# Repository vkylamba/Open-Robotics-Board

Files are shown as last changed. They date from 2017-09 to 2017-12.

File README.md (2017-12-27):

# Open-Robotics-Board
Open robotics development board

## Board Specifications
1. ATmega2560 microcontroller.
2. 6 L293d motor drives chips with terminal blocks to connect motor/LEDs.
3. Ports to connect WiFi, and GPRS.
4. On board 16x2 LCD.
5. On board USB port to program the board, and for serial communication.
6. Can be power from 5V-35V.
7. 5 analog ports with female barrel jacks(2 of them can accept high voltages, and are isolated).

## Board Image
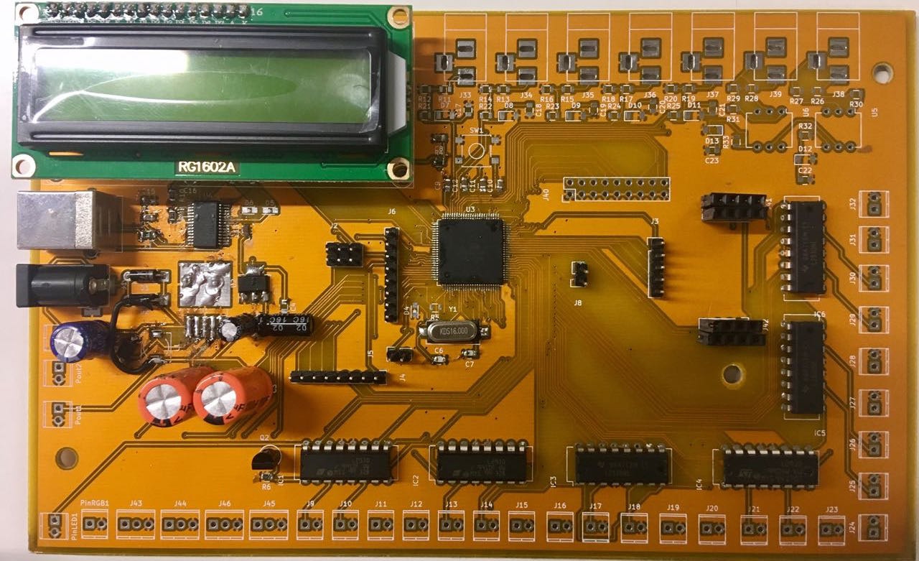
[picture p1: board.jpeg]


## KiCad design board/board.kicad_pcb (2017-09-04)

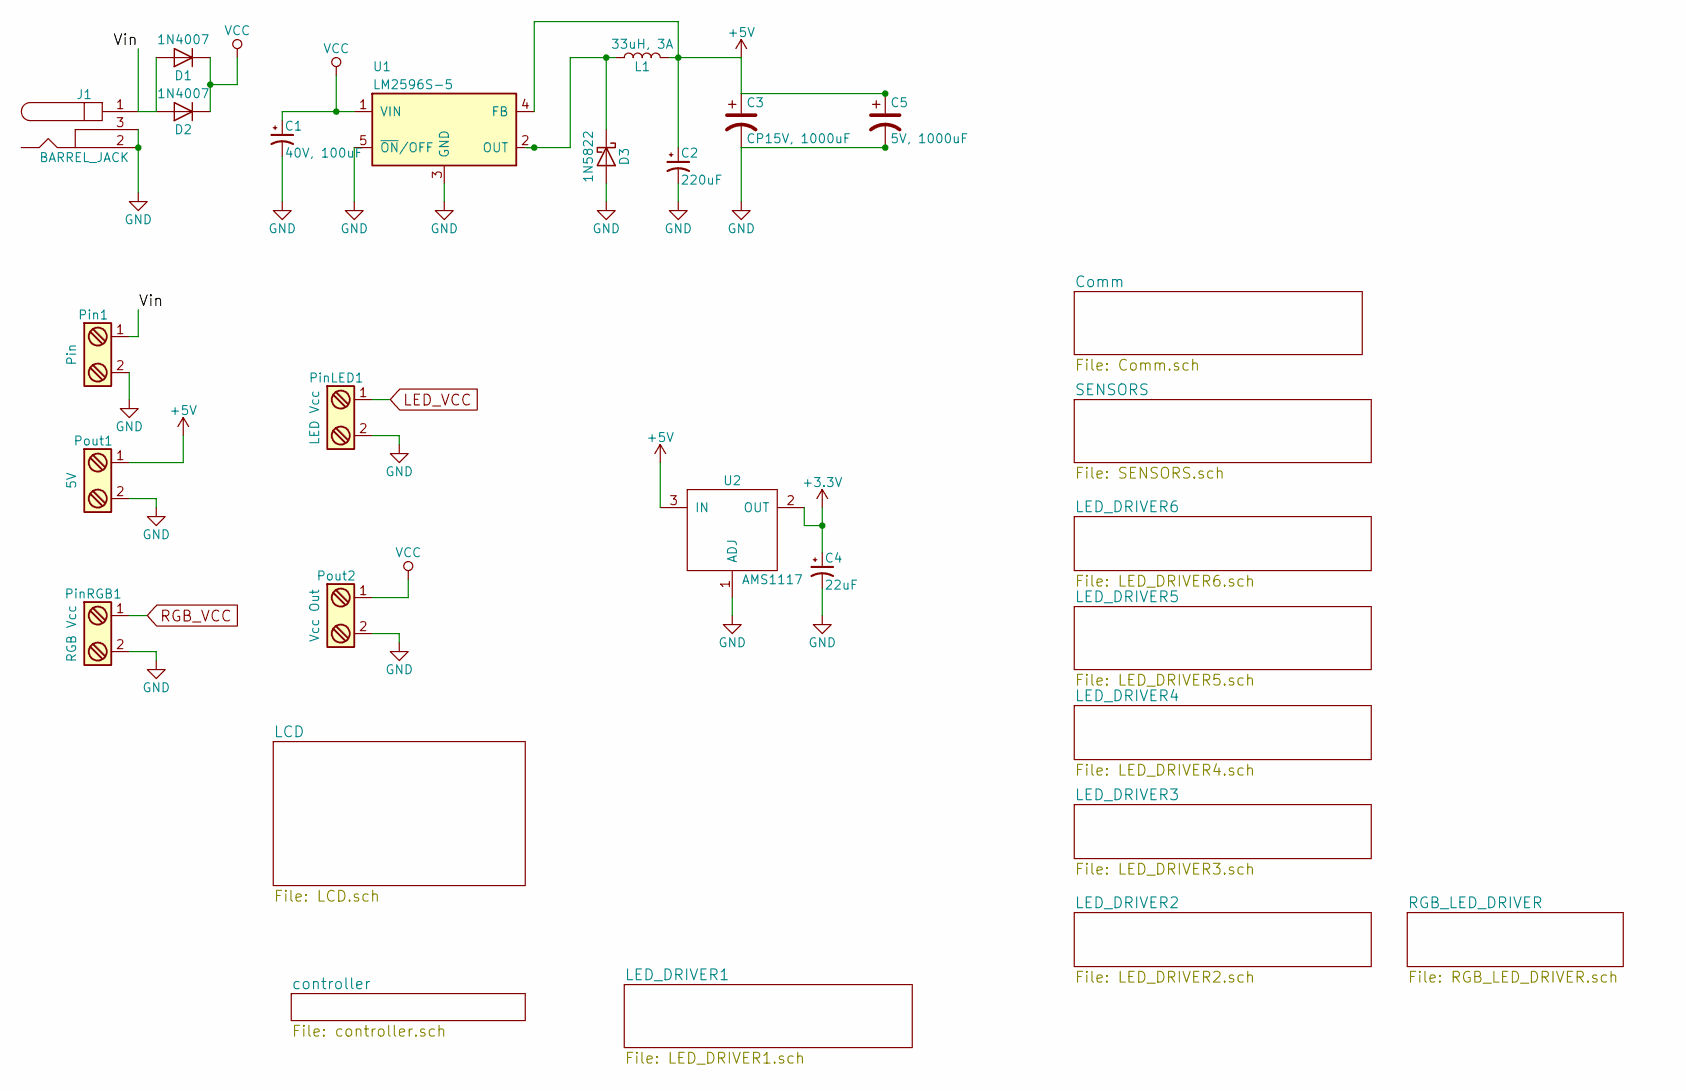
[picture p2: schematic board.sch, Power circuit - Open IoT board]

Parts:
C1: 40V, 100uF; CP_Radial_D5.0mm_P2.50mm
C2: 220uF; CP_Radial_D5.0mm_P2.50mm
C3: CP15V, 1000uF; CP_Radial_D8.0mm_P3.80mm
C4: 22uF; C_0805
C5: 5V, 1000uF; CP_Radial_D8.0mm_P3.80mm
D1, D2: 1N4007; D_DO-41_SOD81_P7.62mm_Horizontal
D3: 1N5822; D_1206
J1: BARREL_JACK
L1: 33uH, 3A; Choke_SMD_6.3x6.3_H3
Pin1: Pin; TerminalBlock_Pheonix_MPT-2.54mm_2pol
PinLED1: LED Vcc; TerminalBlock_Pheonix_MPT-2.54mm_2pol
PinRGB1: RGB Vcc; TerminalBlock_Pheonix_MPT-2.54mm_2pol
Pout1: 5V; TerminalBlock_Pheonix_MPT-2.54mm_2pol
Pout2: Vcc Out; TerminalBlock_Pheonix_MPT-2.54mm_2pol
U1: LM2596S-5; TO-263-5Lead
U2: AMS1117; SOT-223-3Lead_TabPin2

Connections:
+3V3: C4.1, U2.2 (OUT); also elsewhere on the board
+5V: C2.1, C3.1, C5.1, L1.2, Pout1.1, U1.4 (FB), U2.3 (IN); also elsewhere on the board
/Vin: D1.2 (A), D2.2 (A), J1.1, Pin1.1
GND: C1.2, C2.2, C3.2, C4.2, C5.2, D3.2 (A), J1.2, J1.3, Pin1.2, PinLED1.2, PinRGB1.2, Pout1.2, Pout2.2, U1.3 (GND), U1.5 (~ON~/OFF), U2.1 (ADJ); also elsewhere on the board
LED_VCC: PinLED1.1; also elsewhere on the board
unnamed: D3.1 (K), L1.1, U1.2 (OUT)
RGB_VCC: PinRGB1.1; also elsewhere on the board
VCC: C1.1, D1.1 (K), D2.1 (K), Pout2.1, U1.1 (VIN)

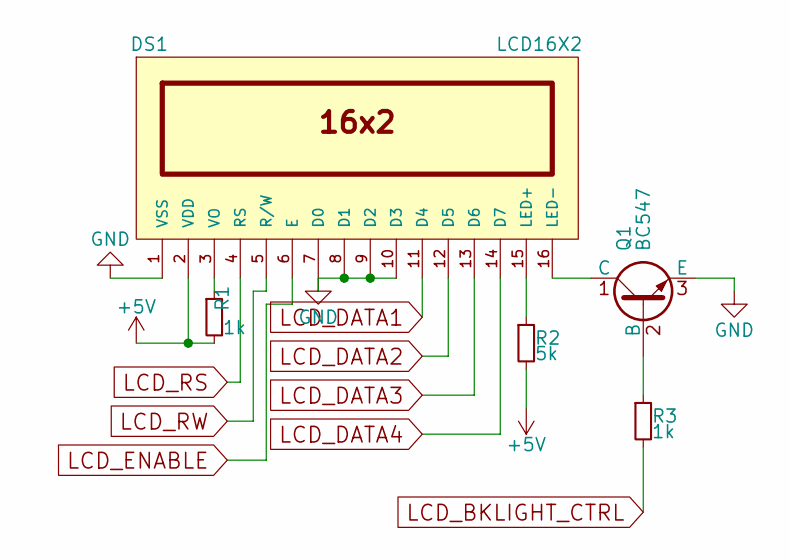
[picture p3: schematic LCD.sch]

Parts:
DS1: LCD16X2; WC1602A
Q1: BC547; TO-92_Inline_Narrow_Oval
R1, R3: 1k; R_0805
R2: 5k; R_0805

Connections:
+5V: DS1.2 (VDD), R1.2, R2.2; also elsewhere on the board
GND: DS1.1 (VSS), DS1.7 (D0), DS1.8 (D1), DS1.9 (D2), DS1.10 (D3), Q1.3 (E); also elsewhere on the board
LCD_BKLIGHT_CTRL: R3.2; also elsewhere on the board
LCD_DATA1: DS1.11 (D4); also elsewhere on the board
LCD_DATA2: DS1.12 (D5); also elsewhere on the board
LCD_DATA3: DS1.13 (D6); also elsewhere on the board
LCD_DATA4: DS1.14 (D7); also elsewhere on the board
LCD_ENABLE: DS1.6 (E); also elsewhere on the board
LCD_RS: DS1.4 (RS); also elsewhere on the board
LCD_RW: DS1.5 (R/W); also elsewhere on the board
unnamed: DS1.3 (VO), R1.1
unnamed: DS1.15 (LED+), R2.1
unnamed: DS1.16 (LED-), Q1.1 (C)
unnamed: Q1.2 (B), R3.1

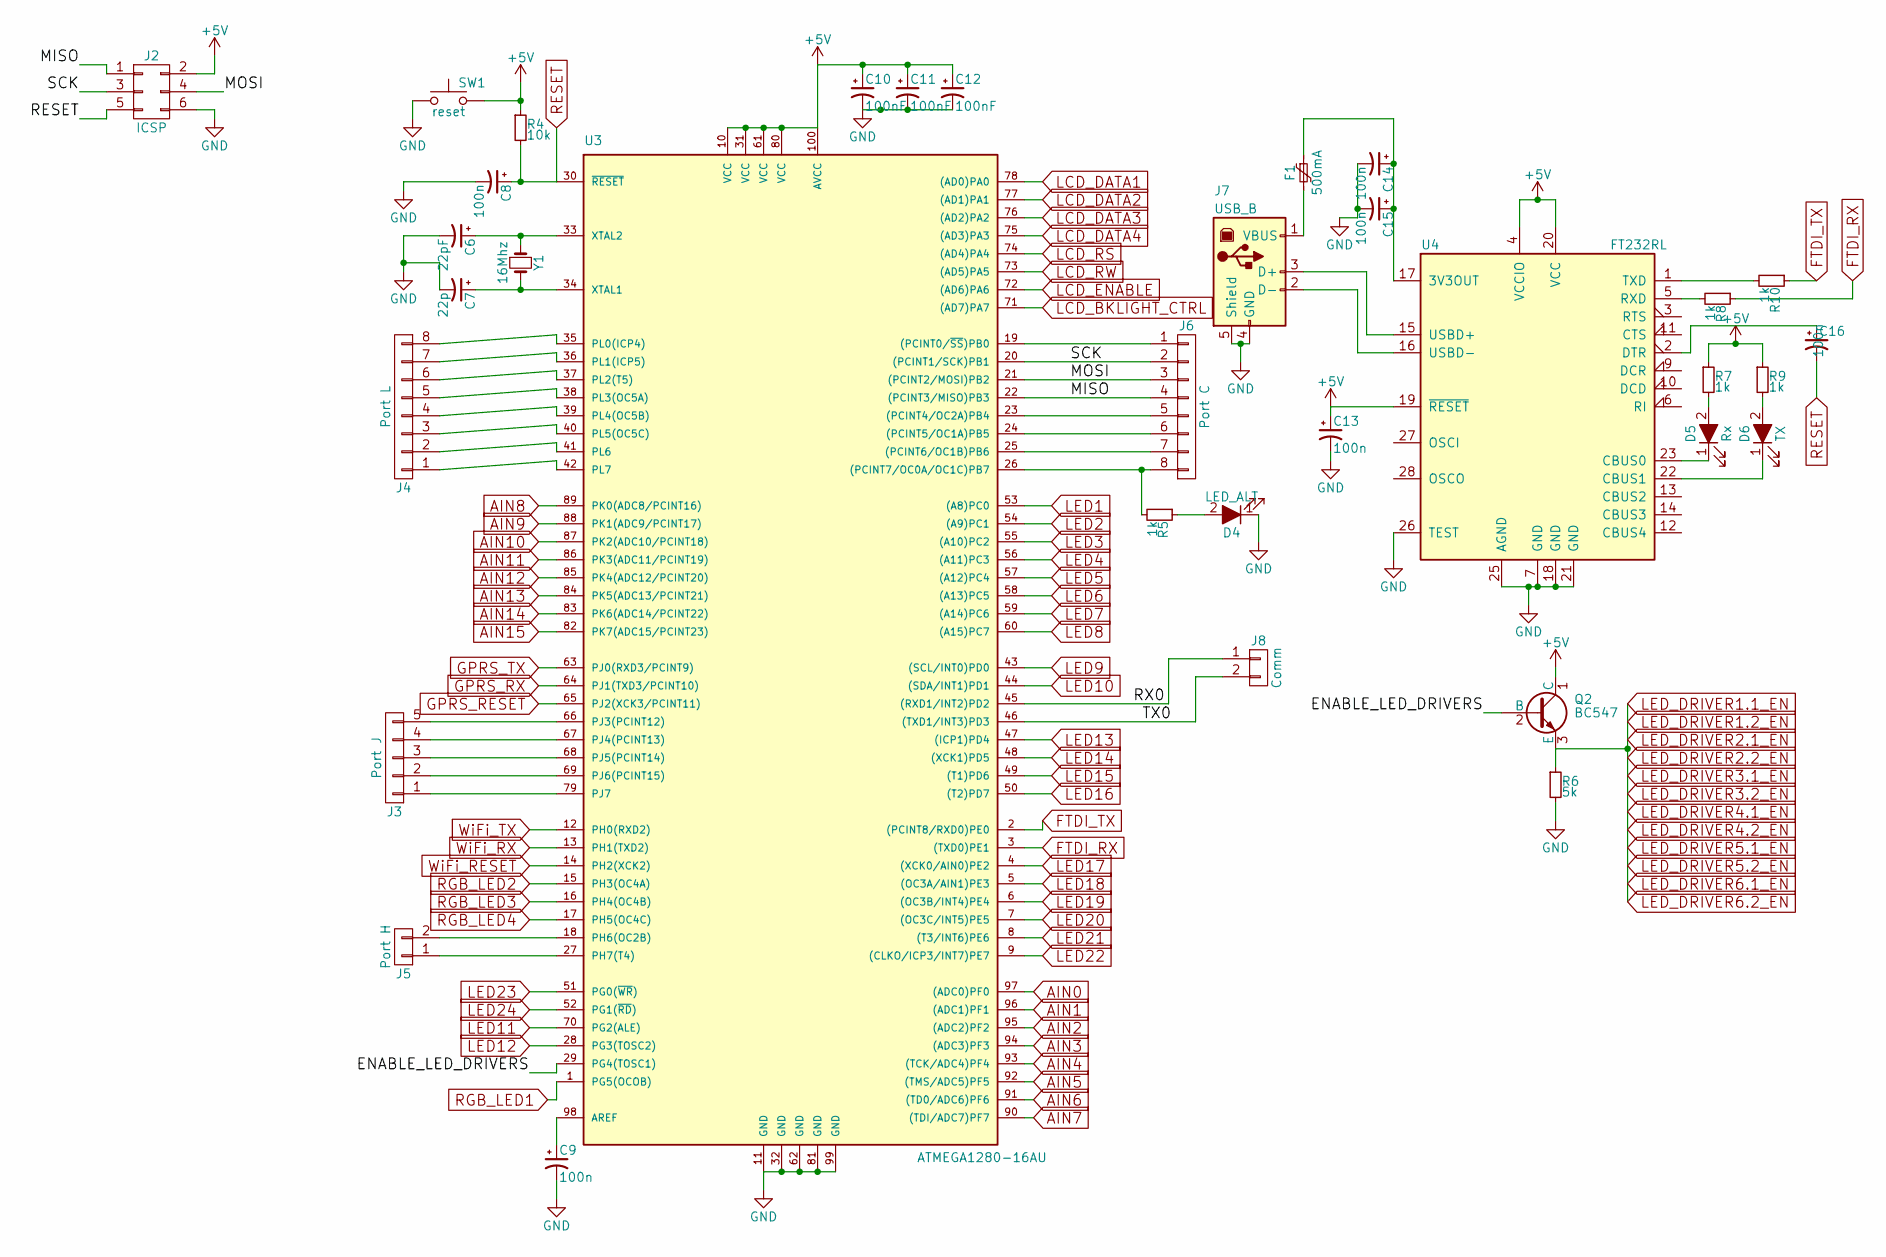
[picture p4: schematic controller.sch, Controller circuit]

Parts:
C6: 22pF; C_0805
C7: 22p; C_0805
C8, C9, C13, C14, C15, C16: 100n; C_0805
C10, C11, C12: 100nF; C_0805
D4: LED_ALT; LED_0805
D5: Rx; LED_0805
D6: TX; LED_0805
F1: 500mA; R_1206
J2: ICSP; Socket_Strip_Straight_2x03
J3: Port J; Pin_Header_Straight_1x05
J4: Port L; Pin_Header_Straight_1x08
J5: Port H; Pin_Header_Straight_1x02
J6: Port C; Pin_Header_Straight_1x08
J7: USB_B
J8: Comm; Pin_Header_Straight_1x02
Q2: BC547; TO-92_Inline_Narrow_Oval
R4: 10k; R_0805
R5, R7, R8, R9, R10: 1k; R_0805
R6: 5k; R_0805
SW1: reset; SW_SPST_B3S-1000
U3: ATMEGA1280-16AU; TQFP-100_14x14mm_Pitch0.5mm
U4: FT232RL; SSOP-28_5.3x10.2mm_Pitch0.65mm
Y1: 16Mhz; Crystal_HC49-SD_SMD

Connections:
+5V: C10.1, C11.1, C12.1, C13.1, J2.2, Q2.1 (C), R4.1, R7.1, R9.1, SW1.2, U3.10 (VCC), U3.31 (VCC), U3.61 (VCC), U3.80 (VCC), U3.100 (AVCC), U4.4 (VCCIO), U4.19 (~RESET~), U4.20 (VCC); also elsewhere on the board
/controller/ENABLE_LED_DRIVERS: Q2.2 (B), U3.29 (PG4(TOSC1))
/controller/MISO: J2.1, J6.4, U3.22 ((PCINT3/MISO)PB3)
/controller/MOSI: J2.4, J6.3, U3.21 ((PCINT2/MOSI)PB2)
/controller/RX0: J8.1, U3.45 ((RXD1/INT2)PD2)
/controller/SCK: J2.3, J6.2, U3.20 ((PCINT1/SCK)PB1)
/controller/TX0: J8.2, U3.46 ((TXD1/INT3)PD3)
AIN0: U3.97 ((ADC0)PF0); also elsewhere on the board
AIN1: U3.96 ((ADC1)PF1); also elsewhere on the board
AIN2: U3.95 ((ADC2)PF2); also elsewhere on the board
AIN3: U3.94 ((ADC3)PF3); also elsewhere on the board
AIN4: U3.93 ((TCK/ADC4)PF4); also elsewhere on the board
AIN5: U3.92 ((TMS/ADC5)PF5); also elsewhere on the board
AIN6: U3.91 ((TD0/ADC6)PF6); also elsewhere on the board
AIN7: U3.90 ((TDI/ADC7)PF7); also elsewhere on the board
AIN8: U3.89 (PK0(ADC8/PCINT16)); also elsewhere on the board
AIN9: U3.88 (PK1(ADC9/PCINT17)); also elsewhere on the board
AIN10: U3.87 (PK2(ADC10/PCINT18)); also elsewhere on the board
AIN11: U3.86 (PK3(ADC11/PCINT19)); also elsewhere on the board
AIN12: U3.85 (PK4(ADC12/PCINT20)); also elsewhere on the board
AIN13: U3.84 (PK5(ADC13/PCINT21)); also elsewhere on the board
AIN14: U3.83 (PK6(ADC14/PCINT22)); also elsewhere on the board
AIN15: U3.82 (PK7(ADC15/PCINT23)); also elsewhere on the board
FTDI_RX: R8.1, U3.3 ((TXD0)PE1)
FTDI_TX: R10.1, U3.2 ((PCINT8/RXD0)PE0)
GND: C6.2, C7.2, C8.2, C9.2, C10.2, C11.2, C12.2, C13.2, C14.2, C15.2, D4.1 (K), J2.6, J7.4 (GND), J7.5 (Shield), R6.2, SW1.1, U3.11 (GND), U3.32 (GND), U3.62 (GND), U3.81 (GND), U3.99 (GND), U4.7 (GND), U4.18 (GND), U4.21 (GND), U4.25 (AGND), U4.26 (TEST); also elsewhere on the board
GPRS_RESET: U3.65 (PJ2(XCK3/PCINT11)); also elsewhere on the board
GPRS_RX: U3.64 (PJ1(TXD3/PCINT10)); also elsewhere on the board
GPRS_TX: U3.63 (PJ0(RXD3/PCINT9)); also elsewhere on the board
LCD_BKLIGHT_CTRL: U3.71 ((AD7)PA7); also elsewhere on the board
LCD_DATA1: U3.78 ((AD0)PA0); also elsewhere on the board
LCD_DATA2: U3.77 ((AD1)PA1); also elsewhere on the board
LCD_DATA3: U3.76 ((AD2)PA2); also elsewhere on the board
LCD_DATA4: U3.75 ((AD3)PA3); also elsewhere on the board
LCD_ENABLE: U3.72 ((AD6)PA6); also elsewhere on the board
LCD_RS: U3.74 ((AD4)PA4); also elsewhere on the board
LCD_RW: U3.73 ((AD5)PA5); also elsewhere on the board
LED1: U3.53 ((A8)PC0); also elsewhere on the board
LED2: U3.54 ((A9)PC1); also elsewhere on the board
LED3: U3.55 ((A10)PC2); also elsewhere on the board
LED4: U3.56 ((A11)PC3); also elsewhere on the board
LED5: U3.57 ((A12)PC4); also elsewhere on the board
LED6: U3.58 ((A13)PC5); also elsewhere on the board
LED7: U3.59 ((A14)PC6); also elsewhere on the board
LED8: U3.60 ((A15)PC7); also elsewhere on the board
LED9: U3.43 ((SCL/INT0)PD0); also elsewhere on the board
LED10: U3.44 ((SDA/INT1)PD1); also elsewhere on the board
LED11: U3.70 (PG2(ALE)); also elsewhere on the board
LED12: U3.28 (PG3(TOSC2)); also elsewhere on the board
LED13: U3.47 ((ICP1)PD4); also elsewhere on the board
LED14: U3.48 ((XCK1)PD5); also elsewhere on the board
LED15: U3.49 ((T1)PD6); also elsewhere on the board
LED16: U3.50 ((T2)PD7); also elsewhere on the board
LED17: U3.4 ((XCK0/AIN0)PE2); also elsewhere on the board
LED18: U3.5 ((OC3A/AIN1)PE3); also elsewhere on the board
LED19: U3.6 ((OC3B/INT4)PE4); also elsewhere on the board
LED20: U3.7 ((OC3C/INT5)PE5); also elsewhere on the board
LED21: U3.8 ((T3/INT6)PE6); also elsewhere on the board
LED22: U3.9 ((CLKO/ICP3/INT7)PE7); also elsewhere on the board
LED23: U3.51 (PG0(~WR~)); also elsewhere on the board
LED24: U3.52 (PG1(~RD~)); also elsewhere on the board
LED_DRIVER1.1_EN: Q2.3 (E), R6.1; also elsewhere on the board
unnamed: C6.1, U3.33 (XTAL2), Y1.1
unnamed: C7.1, U3.34 (XTAL1), Y1.2
unnamed: C9.1, U3.98 (AREF)
unnamed: C14.1, C15.1, F1.1, U4.17 (3V3OUT)
unnamed: C16.1, U4.2 (DTR)
unnamed: D4.2 (A), R5.1
unnamed: D5.1 (K), U4.23 (CBUS0)
unnamed: D5.2 (A), R7.2
unnamed: D6.1 (K), U4.22 (CBUS1)
unnamed: D6.2 (A), R9.2
unnamed: F1.2, J7.1 (VBUS)
unnamed: J3.1, U3.79 (PJ7)
unnamed: J3.2, U3.69 (PJ6(PCINT15))
unnamed: J3.3, U3.68 (PJ5(PCINT14))
unnamed: J3.4, U3.67 (PJ4(PCINT13))
unnamed: J3.5, U3.66 (PJ3(PCINT12))
unnamed: J4.1, U3.42 (PL7)
unnamed: J4.2, U3.41 (PL6)
unnamed: J4.3, U3.40 (PL5(OC5C))
unnamed: J4.4, U3.39 (PL4(OC5B))
unnamed: J4.5, U3.38 (PL3(OC5A))
unnamed: J4.6, U3.37 (PL2(T5))
unnamed: J4.7, U3.36 (PL1(ICP5))
unnamed: J4.8, U3.35 (PL0(ICP4))
unnamed: J5.1, U3.27 (PH7(T4))
unnamed: J5.2, U3.18 (PH6(OC2B))
unnamed: J6.1, U3.19 ((PCINT0/~SS~)PB0)
unnamed: J6.5, U3.23 ((PCINT4/OC2A)PB4)
unnamed: J6.6, U3.24 ((PCINT5/OC1A)PB5)
unnamed: J6.7, U3.25 ((PCINT6/OC1B)PB6)
unnamed: J6.8, R5.2, U3.26 ((PCINT7/OC0A/OC1C)PB7)
unnamed: J7.2 (D-), U4.16 (USBD-)
unnamed: J7.3 (D+), U4.15 (USBD+)
unnamed: R8.2, U4.5 (RXD)
unnamed: R10.2, U4.1 (TXD)
RESET: C8.1, C16.2, J2.5, R4.2, U3.30 (~RESET)
RGB_LED1: U3.1 (PG5(OCOB)); also elsewhere on the board
RGB_LED2: U3.15 (PH3(OC4A)); also elsewhere on the board
RGB_LED3: U3.16 (PH4(OC4B)); also elsewhere on the board
RGB_LED4: U3.17 (PH5(OC4C)); also elsewhere on the board
WiFi_RESET: U3.14 (PH2(XCK2)); also elsewhere on the board
WiFi_RX: U3.13 (PH1(TXD2)); also elsewhere on the board
WiFi_TX: U3.12 (PH0(RXD2)); also elsewhere on the board

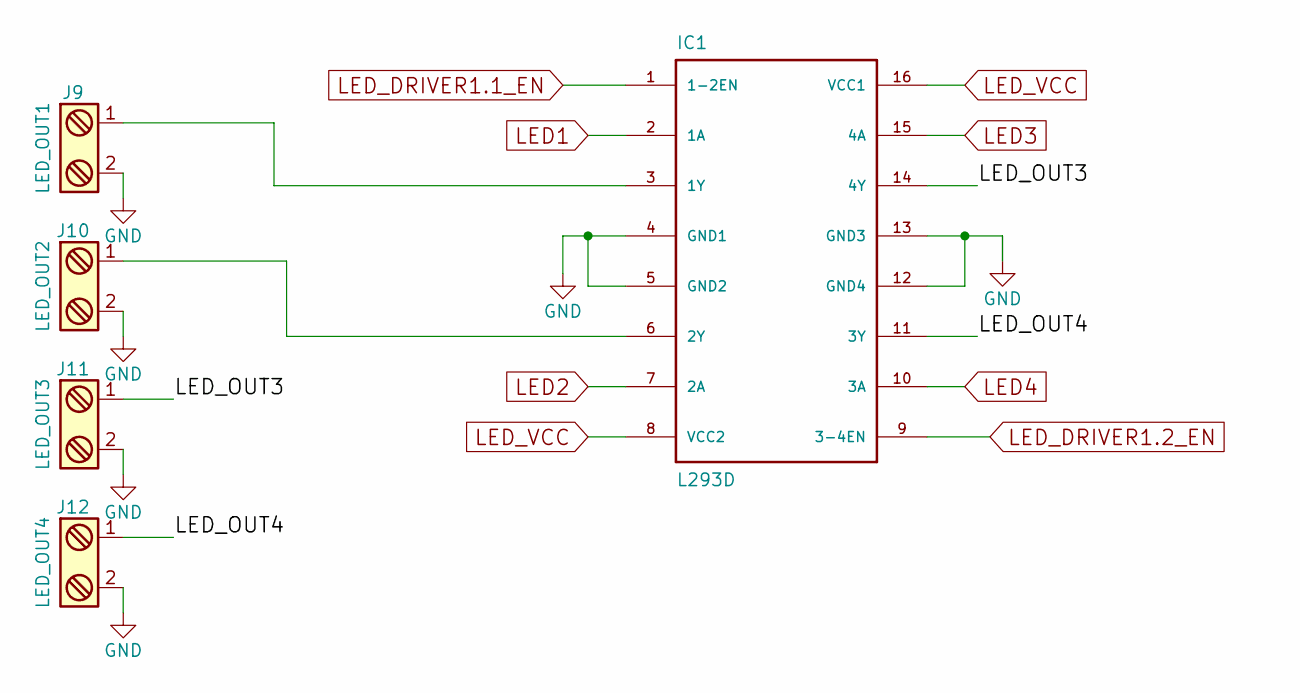
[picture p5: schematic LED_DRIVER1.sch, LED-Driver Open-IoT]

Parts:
IC1: L293D; DIP-16_W7.62mm
J9: LED_OUT1; TerminalBlock_Pheonix_MPT-2.54mm_2pol
J10: LED_OUT2; TerminalBlock_Pheonix_MPT-2.54mm_2pol
J11: LED_OUT3; TerminalBlock_Pheonix_MPT-2.54mm_2pol
J12: LED_OUT4; TerminalBlock_Pheonix_MPT-2.54mm_2pol

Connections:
/LED_DRIVER1/LED_OUT3: IC1.14 (4Y), J11.1
/LED_DRIVER1/LED_OUT4: IC1.11 (3Y), J12.1
GND: IC1.4 (GND1), IC1.5 (GND2), IC1.12 (GND4), IC1.13 (GND3), J9.2, J10.2, J11.2, J12.2; also elsewhere on the board
LED1: IC1.2 (1A); also elsewhere on the board
LED2: IC1.7 (2A); also elsewhere on the board
LED3: IC1.15 (4A); also elsewhere on the board
LED4: IC1.10 (3A); also elsewhere on the board
LED_DRIVER1.1_EN: IC1.1 (1-2EN), IC1.9 (3-4EN); also elsewhere on the board
LED_VCC: IC1.8 (VCC2), IC1.16 (VCC1); also elsewhere on the board
unnamed: IC1.3 (1Y), J9.1
unnamed: IC1.6 (2Y), J10.1

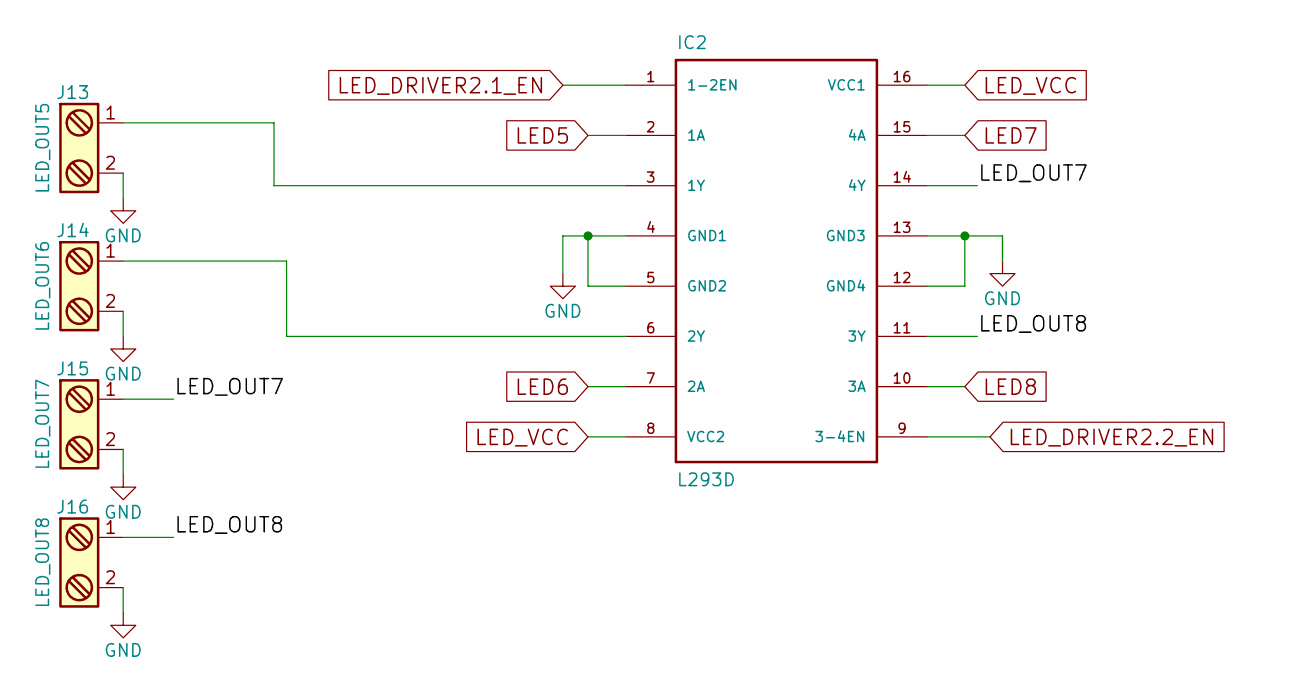
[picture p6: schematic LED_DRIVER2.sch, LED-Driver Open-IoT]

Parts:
IC2: L293D; DIP-16_W7.62mm
J13: LED_OUT5; TerminalBlock_Pheonix_MPT-2.54mm_2pol
J14: LED_OUT6; TerminalBlock_Pheonix_MPT-2.54mm_2pol
J15: LED_OUT7; TerminalBlock_Pheonix_MPT-2.54mm_2pol
J16: LED_OUT8; TerminalBlock_Pheonix_MPT-2.54mm_2pol

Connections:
/LED_DRIVER2/LED_OUT7: IC2.14 (4Y), J15.1
/LED_DRIVER2/LED_OUT8: IC2.11 (3Y), J16.1
GND: IC2.4 (GND1), IC2.5 (GND2), IC2.12 (GND4), IC2.13 (GND3), J13.2, J14.2, J15.2, J16.2; also elsewhere on the board
LED5: IC2.2 (1A); also elsewhere on the board
LED6: IC2.7 (2A); also elsewhere on the board
LED7: IC2.15 (4A); also elsewhere on the board
LED8: IC2.10 (3A); also elsewhere on the board
LED_DRIVER1.1_EN: IC2.1 (1-2EN), IC2.9 (3-4EN); also elsewhere on the board
LED_VCC: IC2.8 (VCC2), IC2.16 (VCC1); also elsewhere on the board
unnamed: IC2.3 (1Y), J13.1
unnamed: IC2.6 (2Y), J14.1

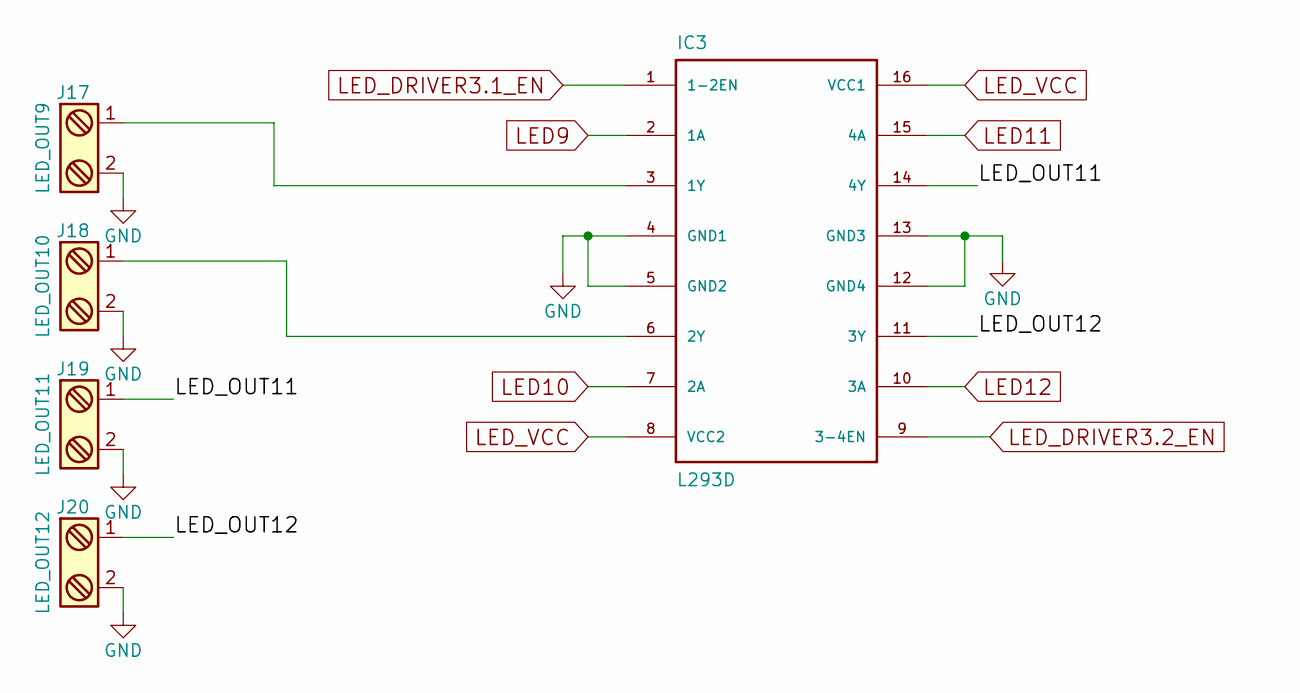
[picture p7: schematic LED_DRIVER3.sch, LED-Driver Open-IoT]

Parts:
IC3: L293D; DIP-16_W7.62mm
J17: LED_OUT9; TerminalBlock_Pheonix_MPT-2.54mm_2pol
J18: LED_OUT10; TerminalBlock_Pheonix_MPT-2.54mm_2pol
J19: LED_OUT11; TerminalBlock_Pheonix_MPT-2.54mm_2pol
J20: LED_OUT12; TerminalBlock_Pheonix_MPT-2.54mm_2pol

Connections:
/LED_DRIVER3/LED_OUT11: IC3.14 (4Y), J19.1
/LED_DRIVER3/LED_OUT12: IC3.11 (3Y), J20.1
GND: IC3.4 (GND1), IC3.5 (GND2), IC3.12 (GND4), IC3.13 (GND3), J17.2, J18.2, J19.2, J20.2; also elsewhere on the board
LED9: IC3.2 (1A); also elsewhere on the board
LED10: IC3.7 (2A); also elsewhere on the board
LED11: IC3.15 (4A); also elsewhere on the board
LED12: IC3.10 (3A); also elsewhere on the board
LED_DRIVER1.1_EN: IC3.1 (1-2EN), IC3.9 (3-4EN); also elsewhere on the board
LED_VCC: IC3.8 (VCC2), IC3.16 (VCC1); also elsewhere on the board
unnamed: IC3.3 (1Y), J17.1
unnamed: IC3.6 (2Y), J18.1

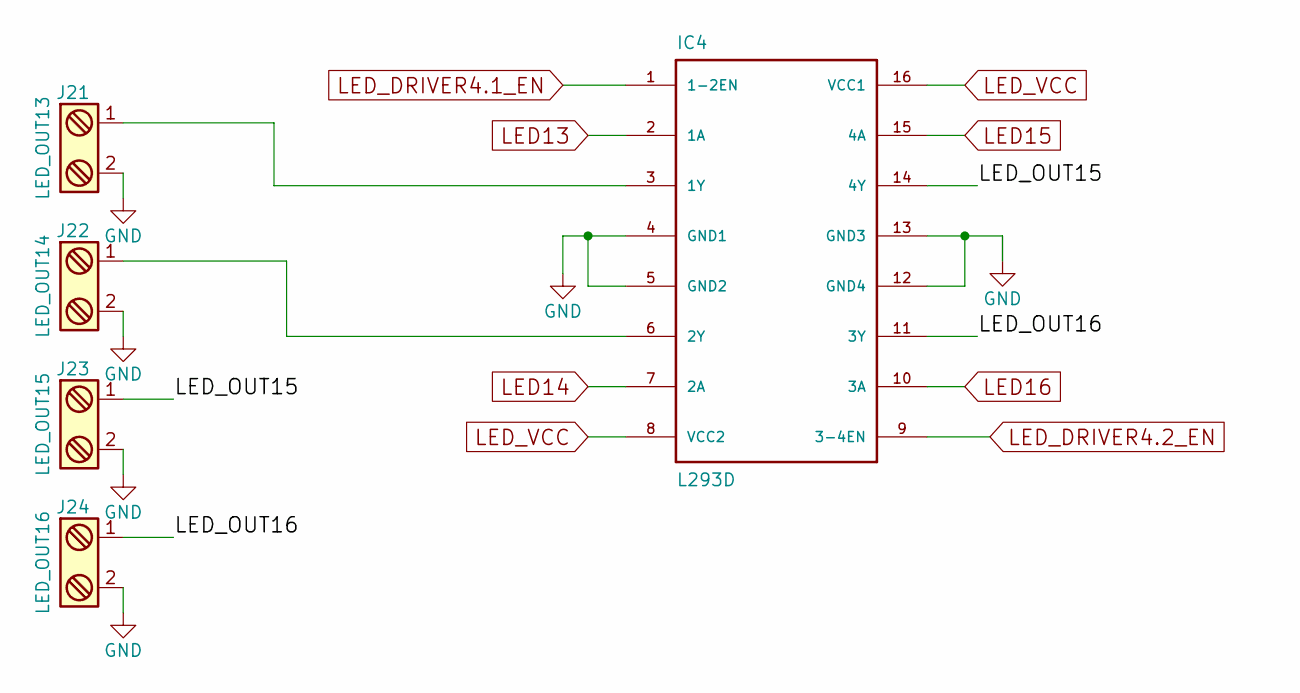
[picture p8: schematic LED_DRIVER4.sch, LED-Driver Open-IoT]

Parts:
IC4: L293D; DIP-16_W7.62mm
J21: LED_OUT13; TerminalBlock_Pheonix_MPT-2.54mm_2pol
J22: LED_OUT14; TerminalBlock_Pheonix_MPT-2.54mm_2pol
J23: LED_OUT15; TerminalBlock_Pheonix_MPT-2.54mm_2pol
J24: LED_OUT16; TerminalBlock_Pheonix_MPT-2.54mm_2pol

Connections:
/LED_DRIVER4/LED_OUT15: IC4.14 (4Y), J23.1
/LED_DRIVER4/LED_OUT16: IC4.11 (3Y), J24.1
GND: IC4.4 (GND1), IC4.5 (GND2), IC4.12 (GND4), IC4.13 (GND3), J21.2, J22.2, J23.2, J24.2; also elsewhere on the board
LED13: IC4.2 (1A); also elsewhere on the board
LED14: IC4.7 (2A); also elsewhere on the board
LED15: IC4.15 (4A); also elsewhere on the board
LED16: IC4.10 (3A); also elsewhere on the board
LED_DRIVER1.1_EN: IC4.1 (1-2EN), IC4.9 (3-4EN); also elsewhere on the board
LED_VCC: IC4.8 (VCC2), IC4.16 (VCC1); also elsewhere on the board
unnamed: IC4.3 (1Y), J21.1
unnamed: IC4.6 (2Y), J22.1

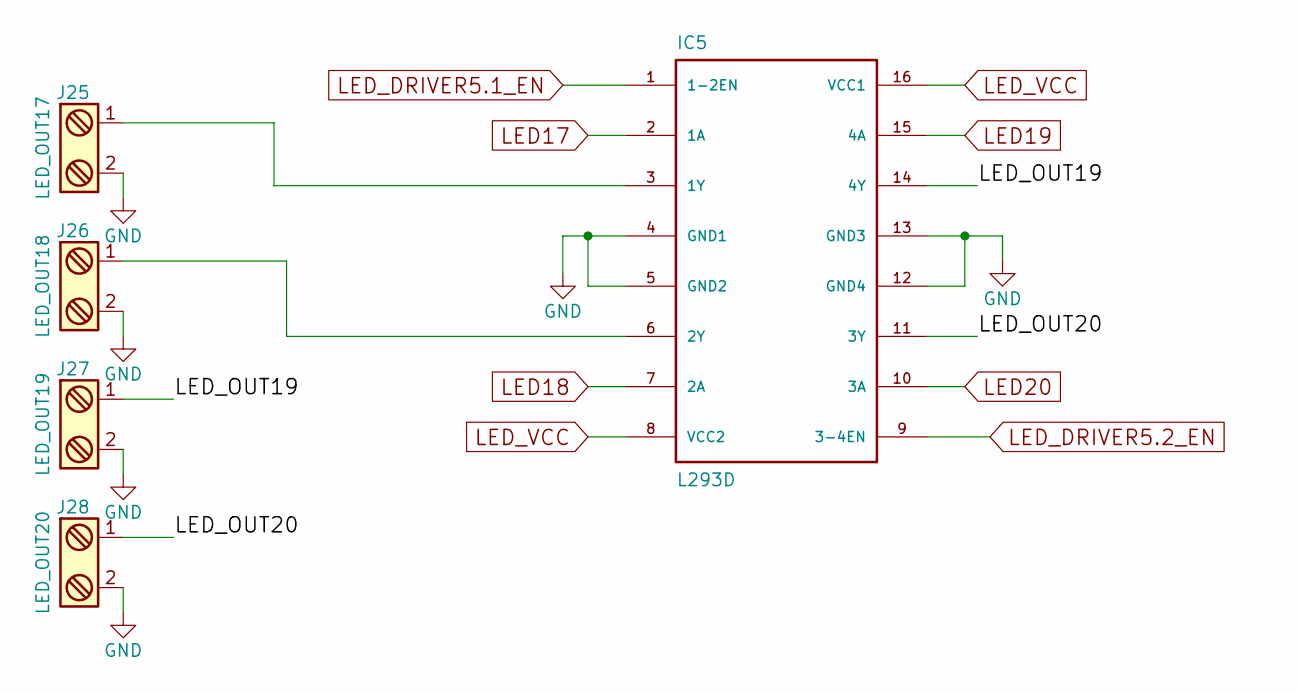
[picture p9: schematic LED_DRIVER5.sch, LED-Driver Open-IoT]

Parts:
IC5: L293D; DIP-16_W7.62mm
J25: LED_OUT17; TerminalBlock_Pheonix_MPT-2.54mm_2pol
J26: LED_OUT18; TerminalBlock_Pheonix_MPT-2.54mm_2pol
J27: LED_OUT19; TerminalBlock_Pheonix_MPT-2.54mm_2pol
J28: LED_OUT20; TerminalBlock_Pheonix_MPT-2.54mm_2pol

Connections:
/LED_DRIVER5/LED_OUT19: IC5.14 (4Y), J27.1
/LED_DRIVER5/LED_OUT20: IC5.11 (3Y), J28.1
GND: IC5.4 (GND1), IC5.5 (GND2), IC5.12 (GND4), IC5.13 (GND3), J25.2, J26.2, J27.2, J28.2; also elsewhere on the board
LED17: IC5.2 (1A); also elsewhere on the board
LED18: IC5.7 (2A); also elsewhere on the board
LED19: IC5.15 (4A); also elsewhere on the board
LED20: IC5.10 (3A); also elsewhere on the board
LED_DRIVER1.1_EN: IC5.1 (1-2EN), IC5.9 (3-4EN); also elsewhere on the board
LED_VCC: IC5.8 (VCC2), IC5.16 (VCC1); also elsewhere on the board
unnamed: IC5.3 (1Y), J25.1
unnamed: IC5.6 (2Y), J26.1

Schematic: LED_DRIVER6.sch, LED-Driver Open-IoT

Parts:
IC6: L293D; DIP-16_W7.62mm
J29: LED_OUT21; TerminalBlock_Pheonix_MPT-2.54mm_2pol
J30: LED_OUT22; TerminalBlock_Pheonix_MPT-2.54mm_2pol
J31: LED_OUT23; TerminalBlock_Pheonix_MPT-2.54mm_2pol
J32: LED_OUT24; TerminalBlock_Pheonix_MPT-2.54mm_2pol

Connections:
/LED_DRIVER6/LED_OUT23: IC6.14 (4Y), J31.1
/LED_DRIVER6/LED_OUT24: IC6.11 (3Y), J32.1
GND: IC6.4 (GND1), IC6.5 (GND2), IC6.12 (GND4), IC6.13 (GND3), J29.2, J30.2, J31.2, J32.2; also elsewhere on the board
LED21: IC6.2 (1A); also elsewhere on the board
LED22: IC6.7 (2A); also elsewhere on the board
LED23: IC6.15 (4A); also elsewhere on the board
LED24: IC6.10 (3A); also elsewhere on the board
LED_DRIVER1.1_EN: IC6.1 (1-2EN), IC6.9 (3-4EN); also elsewhere on the board
LED_VCC: IC6.8 (VCC2), IC6.16 (VCC1); also elsewhere on the board
unnamed: IC6.3 (1Y), J29.1
unnamed: IC6.6 (2Y), J30.1

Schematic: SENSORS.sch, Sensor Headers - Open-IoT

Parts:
C17, C18, C19, C20, C21, C22, C23: 100n; C_0805
D7, D8, D9, D10, D11, D12, D13: 1n4733a; D_1206
J33: Ain-0; BARREL_JACK
J34: Ain-1; BARREL_JACK
J35: Ain-2; BARREL_JACK
J36: Ain-3; BARREL_JACK
J37: Ain-4; BARREL_JACK
J38: Ain-6; BARREL_JACK
J39: Ain-5; BARREL_JACK
J40: CONN_02X09; Pin_Header_Straight_2x09
R11, R13, R15, R17, R19, R26, R28: 100k; R_0805
R12, R14, R16, R18, R20, R32, R33: 10k; R_0805
R21, R22, R23, R24, R25: 1k; R_0805
R27, R29: 50k; R_0805
R30, R31: 220k; R_0805
U5, U6: 4n25; DIP-6_W7.62mm

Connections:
+5V: U5.5, U6.5; also elsewhere on the board
AIN0: C17.1, D7.1 (K), R21.1; also elsewhere on the board
AIN1: C18.1, D8.1 (K), R22.1; also elsewhere on the board
AIN2: C19.1, D9.1 (K), R23.1; also elsewhere on the board
AIN3: C20.1, D10.1 (K), R24.1; also elsewhere on the board
AIN4: C21.1, D11.1 (K), R25.1; also elsewhere on the board
AIN5: C23.1, D13.1 (K), R33.1, U6.4; also elsewhere on the board
AIN6: C22.1, D12.1 (K), R32.1, U5.4; also elsewhere on the board
AIN7: J40.2; also elsewhere on the board
AIN8: J40.4; also elsewhere on the board
AIN9: J40.6; also elsewhere on the board
AIN10: J40.8; also elsewhere on the board
AIN11: J40.10; also elsewhere on the board
AIN12: J40.12; also elsewhere on the board
AIN13: J40.14; also elsewhere on the board
AIN14: J40.16; also elsewhere on the board
AIN15: J40.18; also elsewhere on the board
GND: C17.2, C18.2, C19.2, C20.2, C21.2, C22.2, C23.2, D7.2 (A), D8.2 (A), D9.2 (A), D10.2 (A), D11.2 (A), D12.2 (A), D13.2 (A), J33.3, J34.3, J35.3, J36.3, J37.3, J40.1, J40.3, J40.5, J40.7, J40.9, J40.11, J40.13, J40.15, J40.17, R12.2, R14.2, R16.2, R18.2, R20.2, R32.2, R33.2; also elsewhere on the board
unnamed: J33.1, R11.1
unnamed: J34.1, R13.1
unnamed: J35.1, R15.1
unnamed: J36.1, R17.1
unnamed: J37.1, R19.1
unnamed: J38.1, R26.1
unnamed: J38.3, R27.2, U5.2
unnamed: J39.1, R28.1
unnamed: J39.3, R29.2, U6.2
unnamed: R11.2, R12.1, R21.2
unnamed: R13.2, R14.1, R22.2
unnamed: R15.2, R16.1, R23.2
unnamed: R17.2, R18.1, R24.2
unnamed: R19.2, R20.1, R25.2
unnamed: R26.2, R27.1, R30.2
unnamed: R28.2, R29.1, R31.2
unnamed: R30.1, U5.1
unnamed: R31.1, U6.1

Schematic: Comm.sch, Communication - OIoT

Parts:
J41: WiFi; Pin_Header_Straight_2x04
J42: GPRS; Pin_Header_Straight_2x04

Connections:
+3V3: J41.2, J42.2; also elsewhere on the board
GND: J41.7, J42.7; also elsewhere on the board
GPRS_CHPD: J42.6
GPRS_GPIO0: J42.3
GPRS_GPIO2: J42.5
GPRS_RESET: J42.4; also elsewhere on the board
GPRS_RX: J42.1; also elsewhere on the board
GPRS_TX: J42.8; also elsewhere on the board
WiFi_CHPD: J41.6
WiFi_GPIO0: J41.3
WiFi_GPIO2: J41.5
WiFi_RESET: J41.4; also elsewhere on the board
WiFi_RX: J41.1; also elsewhere on the board
WiFi_TX: J41.8; also elsewhere on the board

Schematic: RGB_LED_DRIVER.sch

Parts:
J43: RGB1; TerminalBlock_Pheonix_MPT-2.54mm_3pol
J44: RGB2; TerminalBlock_Pheonix_MPT-2.54mm_3pol
J45: RGB4; TerminalBlock_Pheonix_MPT-2.54mm_3pol
J46: RGB3; TerminalBlock_Pheonix_MPT-2.54mm_3pol

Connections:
GND: J43.3, J44.3, J45.3, J46.3; also elsewhere on the board
RGB_LED1: J43.2; also elsewhere on the board
RGB_LED2: J44.2; also elsewhere on the board
RGB_LED3: J46.2; also elsewhere on the board
RGB_LED4: J45.2; also elsewhere on the board
RGB_VCC: J43.1, J44.1, J45.1, J46.1; also elsewhere on the board

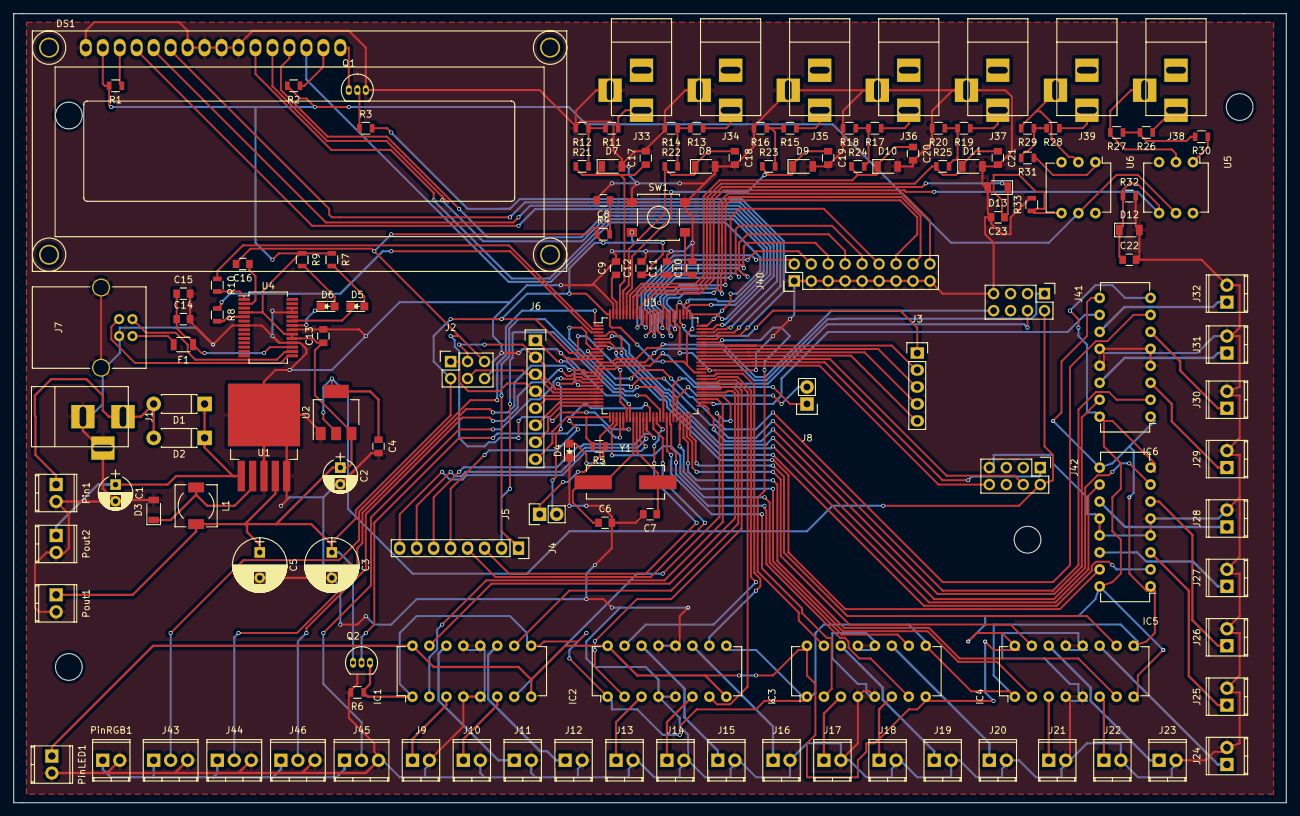
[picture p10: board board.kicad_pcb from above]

Board: 2 copper layers, 190.5 x 118.1 mm, 139 parts (0 on the bottom side), 157 nets.

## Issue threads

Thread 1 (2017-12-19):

Power circuit is not working

vkylamba, 2017-12-19:

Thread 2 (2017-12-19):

The reset switch is not working

vkylamba, 2017-12-19:

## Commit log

2017-09-04 Added board design files
    [Comm.sch, LCD.sch, LED_DRIVER1.sch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]
2017-12-27 Added Board Image
